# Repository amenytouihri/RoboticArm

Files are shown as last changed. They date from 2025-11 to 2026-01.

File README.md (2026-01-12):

# 🤖 Parallel Robotic Arm

A **2 Degree of Freedom (2-DOF)** robotic arm designed to draw shapes from a predefined set of points.
The system uses **two micro servo motors** for actuation, controlled by an **Arduino Uno** and an **L298N motor driver**.

Each arm segment has a **reach of 78 mm**, with a focus on tidy wiring, compact assembly, and stable mounting of all components.

## 🩺 Context

This project is developed under the **Applied Medical Robotics** module, with inspiration from **robotic-assisted surgical systems** such as:

* Eye dissection
* Colon dissection
* Microvascular / Reconstructive surgery

## ⚙️ Requirements

* **Robust** – stable operation and solid mechanical structure
* **Lightweight** – easy to move and mount
* **Precise** – smooth and accurate positioning
* **Creative** – adaptable to different control and testing scenarios

## 🧩 Components

* Arduino Uno
* L298N Motor Driver
* 2× EMG30 Motors
* Custom 3D-printed or laser-cut arm structure (78 mm reach per arm)

## 📐 Features

* Two-axis motion (2-DOF)
* Controlled shape drawing from coordinate data
* Modular design for experimentation
* Clean and secure wiring setup

## 👩🏻‍💻 Software Architecture 
Python GUI
   ↓  (Serial: "A,B")
Arduino Controller
   ├── Encoder Reading
   ├── Angle Estimation (Virtual Target Generator)
   ├── PID Motor Control
   ├── DC Motors + Encoders
   └── Position Feedback

## 🛠️ CAD 
Link for the CAD files: https://a360.co/4qQ7mWJ

## 📄 License

This project is licensed under the [MIT License](https://choosealicense.com/licenses/mit/).

This project is part of the 7MRI0060 Applied Medical Robotics module @King's College London

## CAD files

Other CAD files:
CAD/ALL+COMPONENTS+TOGETHER.dwg
CAD/ALL+COMPONENTS+TOGETHER.f3z

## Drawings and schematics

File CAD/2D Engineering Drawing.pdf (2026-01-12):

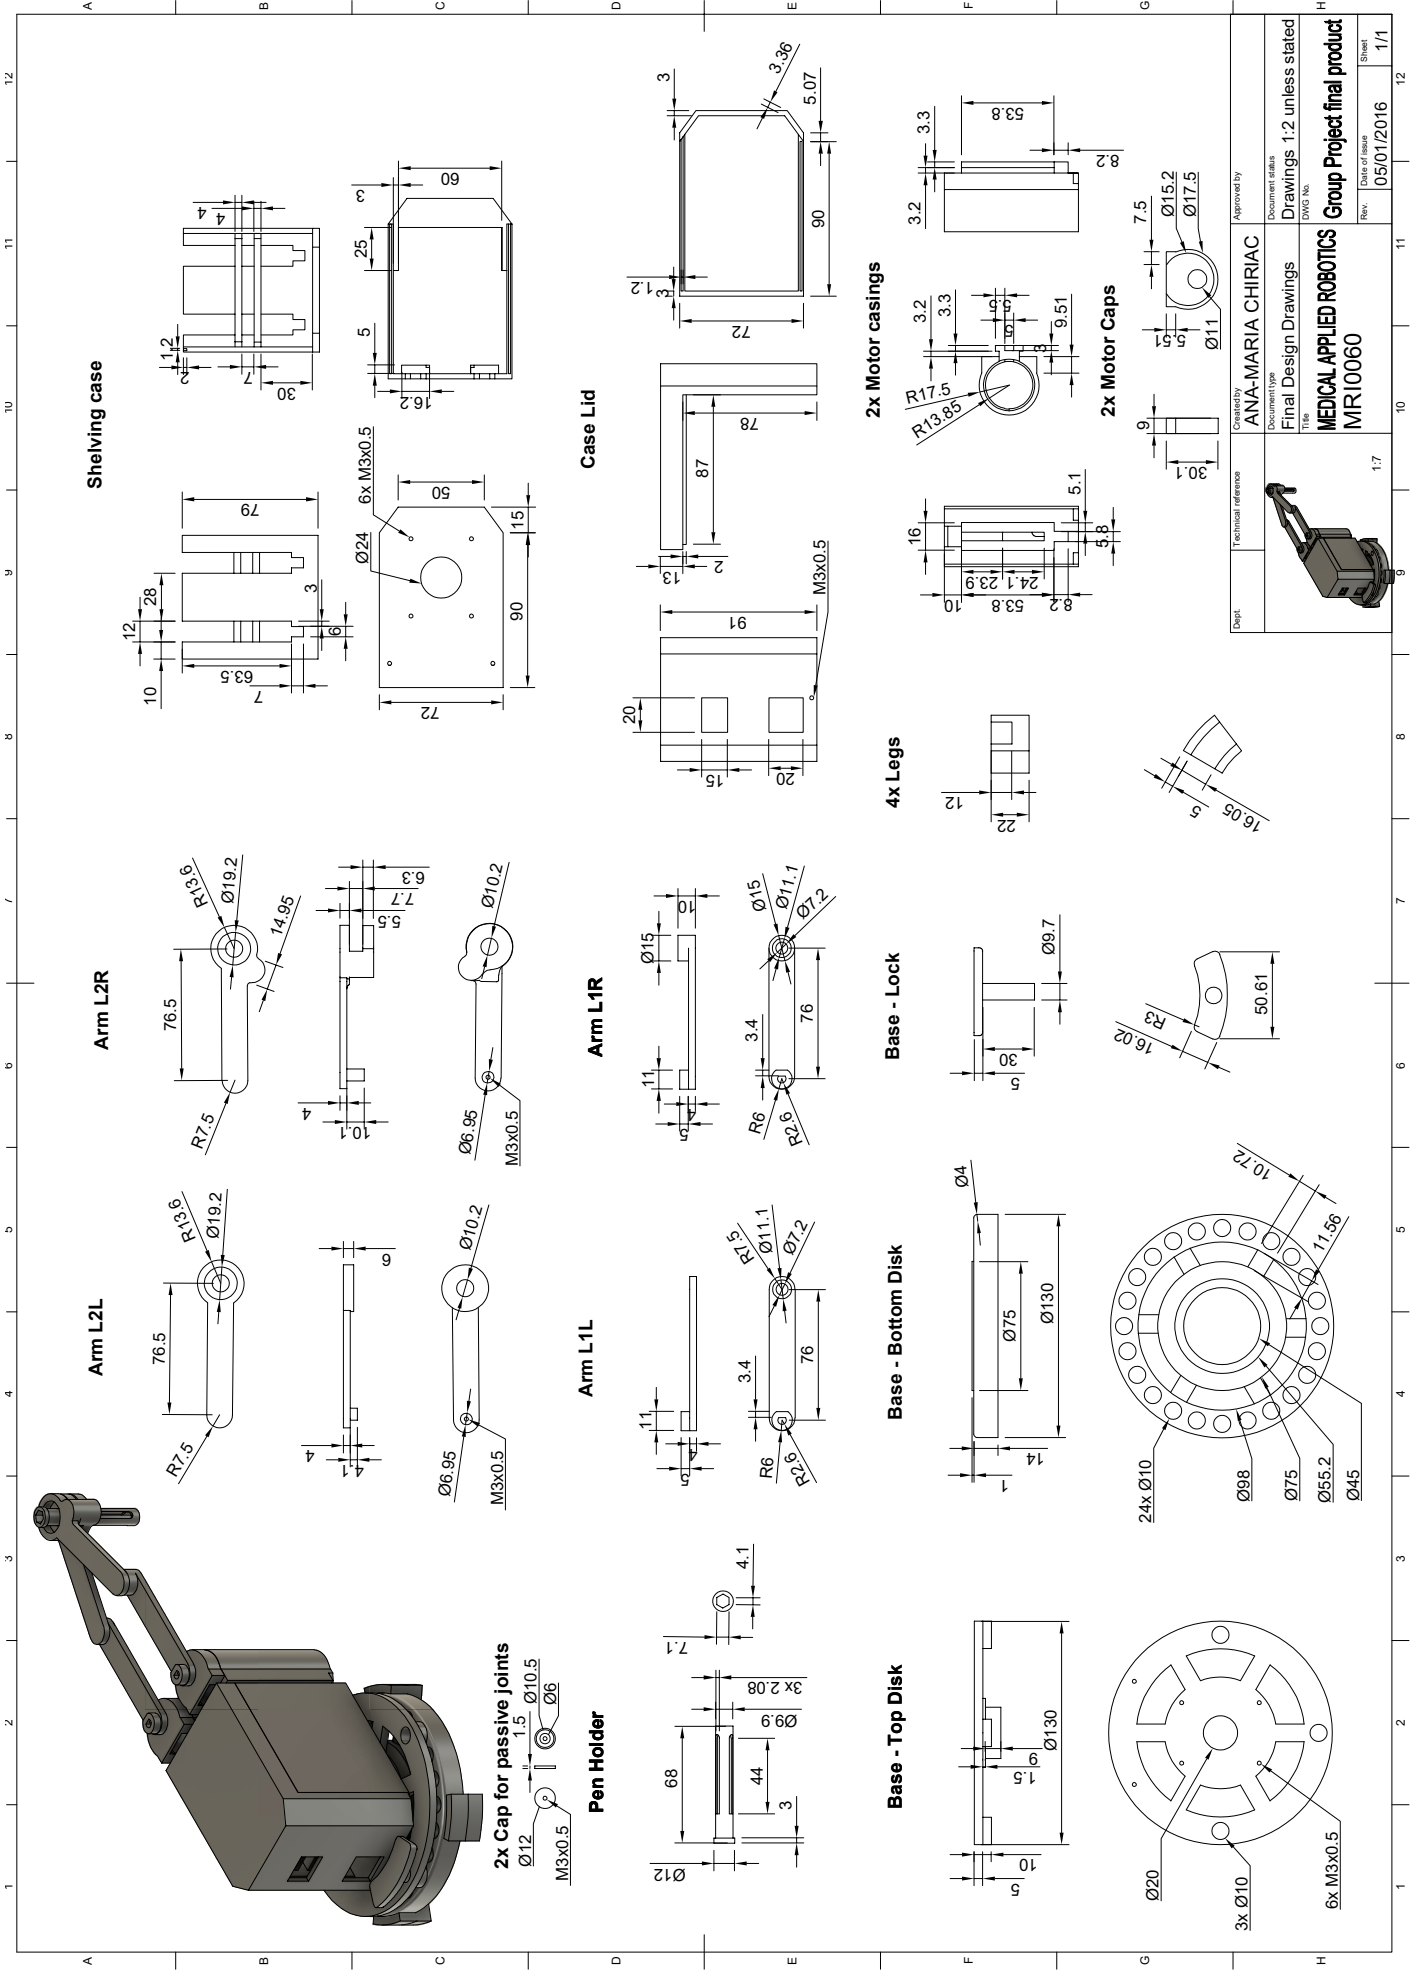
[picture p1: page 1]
4 1. Pen Holder; Ø6.95 Ø10.2 M3x0.5 Arm L1R 11 Ø15; 6. 3.476 Arm L2L; Ø10.2 Arm L1L 11

H Dept. Technical reference Created by Approved by Document type Document status Title DWG No. Rev. Date of issue Sheet 05/01/2016 Drawings 1:2 unless stated Final Design Drawings 1/1 MRI0060 1:7 ANA-MARIA CHIRIAC Ø130

1 .56 Base - Top Disk Base - Bottom Disk Ø9.7

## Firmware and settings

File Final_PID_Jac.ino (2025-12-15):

/*
  ==============================================================
  Dual-Motor Robotic Arm Controller
  Version: Virtual Target Enabled
  ==============================================================
  - Controls TWO DC motors (Motor A & Motor B)
  - Each motor has an encoder for position feedback
  - Uses PID control to reach desired angles
  - Uses a "virtual target" to avoid sudden jumps
  - Receives commands from a PC (e.g. Python GUI) via Serial:
        "angleA,angleB"
  - Designed for linked / parallel robotic arms
*/

///////////////////////////////////////////////////////////////
// ENCODER SETTINGS
///////////////////////////////////////////////////////////////

// Encoder pin definitions
// Each motor has a quadrature encoder (A + B channels)
#define ENC_A_A 2   // Encoder A, channel A (interrupt pin)
#define ENC_A_B 4   // Encoder A, channel B
#define ENC_B_A 3   // Encoder B, channel A (interrupt pin)
#define ENC_B_B 6   // Encoder B, channel B

// Encoder resolution
// CPR = Counts Per Revolution (measured experimentally)
const float CPR = 187.0;

// Conversion factor: encoder ticks → degrees
// one encoder tick corresponds to this many degrees of shaft rotation.
// CPR (Counts Per Revolution) = Number of encoder ticks generated for one full rotation
const float DEG_PER_TICK = 360.0 / CPR;

// Encoder counters (updated inside interrupts)
// volatile = tells compiler this can change at any time
volatile long counterA = 0;
volatile long counterB = 0;

// Encoder value at startup (used as "home" reference)
long homeCountA = 0;
long homeCountB = 0;

// Last encoder A-channel state (for direction detection)
int lastAState, lastBState;

// Current motor positions in degrees
// We ASSUME the physical arm is placed at 90° at startup
float positionA = 90.0;
float positionB = 90.0;

// Direction correction for each motor
// Use +1 or -1 depending on how the motor/encoder is mounted
const int DIR_SIGN_A = +1;
const int DIR_SIGN_B = -1;

// Zone where we enforce minimum PWM
// Prevents motors from stalling when error is still large
const float MOVE_ZONE = 3.0;

///////////////////////////////////////////////////////////////
// MOTOR SETTINGS
///////////////////////////////////////////////////////////////

// Motor A pins (H-bridge)
const int mA_in1 = 7;
const int mA_in2 = 8;
const int mA_pwm = 5;

// Motor B pins (H-bridge)
const int mB_in1 = 9;
const int mB_in2 = 10;
const int mB_pwm = 11;

///////////////////////////////////////////////////////////////
// PID SETTINGS
///////////////////////////////////////////////////////////////

// PID gains for Motor A
float KpA = 2.6455;
float KiA = 0.8;
float KdA = 0.1242;

// PID gains for Motor B
float KpB = 2.85;
float KiB = 0.6;
float KdB = 0.5;

// Small error range where motor is considered "close enough"
float deadzone = 0.2;

// PID memory terms
float prevErrorA = 0.0;
float integralA  = 0.0;
float prevErrorB = 0.0;
float integralB  = 0.0;

///////////////////////////////////////////////////////////////
// MOTION SMOOTHING (VIRTUAL TARGET SYSTEM)
///////////////////////////////////////////////////////////////

// Current PWM output values (for smooth ramping)
int pwmA_current = 0;
int pwmB_current = 0;

// PWM limits
const int MAX_PWM     = 100;
const int MIN_PWM     = 30;
const int pwmRampStep = 10;   // max PWM change per loop

// REAL target angles (from Serial commands)
float targetA  = 90.0;
float targetB  = 90.0;

// VIRTUAL target angles
// These slowly move toward the real target
float virtualA = 90.0;
float virtualB = 90.0;

// Control loop timing
const float LOOP_DT_SEC           = 0.05; // 50 ms loop
const float MAX_SPEED_DEG_PER_SEC = 10.0; // virtual motion speed

///////////////////////////////////////////////////////////////
// SYSTEM STATE
///////////////////////////////////////////////////////////////

// Prevents motors from moving until first Serial command arrives
bool firstCommandReceived = false;

// Onboard LED (optional debug)
const int ledPin = 13;

///////////////////////////////////////////////////////////////
// SETUP
///////////////////////////////////////////////////////////////
void setup() {

  // Start serial communication
  Serial.begin(115200);
  Serial.setTimeout(10);

  pinMode(ledPin, OUTPUT);

  // Encoder inputs
  pinMode(ENC_A_A, INPUT_PULLUP);
  pinMode(ENC_A_B, INPUT_PULLUP);
  pinMode(ENC_B_A, INPUT_PULLUP);
  pinMode(ENC_B_B, INPUT_PULLUP);

  // Read initial encoder states
  lastAState = digitalRead(ENC_A_A);
  lastBState = digitalRead(ENC_B_A);

  // Attach interrupts to encoder A channels
  attachInterrupt(digitalPinToInterrupt(ENC_A_A), updateEncoderA, CHANGE);
  attachInterrupt(digitalPinToInterrupt(ENC_B_A), updateEncoderB, CHANGE);

  // Motor outputs
  pinMode(mA_in1, OUTPUT);
  pinMode(mA_in2, OUTPUT);
  pinMode(mA_pwm, OUTPUT);

  pinMode(mB_in1, OUTPUT);
  pinMode(mB_in2, OUTPUT);
  pinMode(mB_pwm, OUTPUT);

  delay(300); // let system settle

  // Capture encoder values as "home"
  homeCountA = counterA;
  homeCountB = counterB;

  // Initialize all angles at 90°
  positionA = positionB = 90.0;
  targetA   = targetB   = 90.0;
  virtualA  = virtualB  = 90.0;

  Serial.println("System ready.");
}

///////////////////////////////////////////////////////////////
// MAIN LOOP
///////////////////////////////////////////////////////////////
void loop() {

  ///////////////////////////////////////////////////////////////
  // 1) READ SERIAL COMMAND
  ///////////////////////////////////////////////////////////////
  // Expected format: "angleA,angleB"
  if (Serial.available()) {
    String data = Serial.readStringUntil('\n');
    data.trim();
  /*  1) parses a serial command in the form angleA,angleB
      2)converts both values to numerical targets
      3)enables motion only after a valid command is received */ 
    int comma = data.indexOf(',');
    if (comma > 0) {
      targetA = data.substring(0, comma).toFloat();
      targetB = data.substring(comma + 1).toFloat();
      firstCommandReceived = true;
    }
  }

  // Safety: do nothing until first command arrives
  if (!firstCommandReceived) {
    analogWrite(mA_pwm, 0);
    analogWrite(mB_pwm, 0);
    return;
  }

  ///////////////////////////////////////////////////////////////
  //2) ENCODER → CURRENT POSITION
  ///////////////////////////////////////////////////////////////
  long rawA, rawB;
  // Local copies of encoder counters

  // Read encoder counts atomically
  noInterrupts();  //Temporarily pauses all interrupt service routines
  rawA = counterA; // Copies the current encoder counts
  rawB = counterB;
  interrupts(); //Restores normal interrupt operation
  // This was used bc "long" is multi-byte on Arduino ISRs could update it mid-read
  // Converts the raw encoder count of Motor into a real angular position in degrees
  //relative to a known starting position of 90°.
  positionA = 90.0 + DIR_SIGN_A * (rawA - homeCountA) * DEG_PER_TICK;
  positionB = 90.0 + DIR_SIGN_B * (rawB - homeCountB) * DEG_PER_TICK;

  ///////////////////////////////////////////////////////////////
  // 3) VIRTUAL TARGET RAMPING
  // Limit how fast the target angle can change per control loop
  // This prevents sudden jumps from IK and enforces a maximum angular speed
  ///////////////////////////////////////////////////////////////
  /*MAX_SPEED_DEG_PER_SEC = maximum allowed angular speed (degrees per second)
  LOOP_DT_SEC = duration of one control loop iteration (seconds)
  maxStep = maximum angle change allowed in one loop*/
  float maxStep = MAX_SPEED_DEG_PER_SEC * LOOP_DT_SEC;

  if (fabs(targetA - virtualA) > 0.01) {
    // Compute a bounded step toward the real target
    float step = constrain(targetA - virtualA, -maxStep, maxStep);
    // Move virtual target gradually
    virtualA += step;
  }

  if (fabs(targetB - virtualB) > 0.01) {
    float step = constrain(targetB - virtualB, -maxStep, maxStep);
    virtualB += step;
  }

  ///////////////////////////////////////////////////////////////
  // 4) PID CONTROL (USING VIRTUAL TARGETS)
  ///////////////////////////////////////////////////////////////
  /*runs the full PID control loop for Motor, 
  using the virtual target angle and the current measured position, 
  and directly drives the motor pins with smooth PWM output.  */
  controlMotor(
    virtualA, positionA,
    prevErrorA, integralA,
    pwmA_current,
    mA_in1, mA_in2, mA_pwm,
    KpA, KiA, KdA
  );

  controlMotor(
    virtualB, positionB,
    prevErrorB, integralB,
    pwmB_current,
    mB_in1, mB_in2, mB_pwm,
    KpB, KiB, KdB
  );

  ///////////////////////////////////////////////////////////////
  // 5) DEBUG OUTPUT
  ///////////////////////////////////////////////////////////////
  Serial.print("A: ");
  Serial.print(positionA, 2);
  Serial.print(" | PWM: ");
  Serial.print(pwmA_current);
  Serial.print(" | VTarget: ");
  Serial.print(virtualA, 2);
  Serial.print(" | Error: ");
  Serial.print(virtualA - positionA, 2);

  Serial.print(" || B: ");
  Serial.print(positionB, 2);
  Serial.print(" | PWM: ");
  Serial.print(pwmB_current);
  Serial.print(" | VTarget: ");
  Serial.print(virtualB, 2);
  Serial.print(" | Error: ");
  Serial.println(virtualB - positionB, 2);

  delay(50); // loop timing
}

///////////////////////////////////////////////////////////////
// PID MOTOR CONTROL FUNCTION
///////////////////////////////////////////////////////////////
/*
one complete closed-loop controller for a single motor:
  compares desired angle vs measured angle
  computes a PID control output
  smooths the PWM
  sets motor direction and speed via an H-bridge
*/ 
void controlMotor(
  float target, float position,
  float &prevError, float &integral,
  int &pwmCurrent,
  int in1, int in2, int pwmPin,
  float Kp, float Ki, float Kd
) {
  float error = target - position;
  float derivative = error - prevError;

  // Deadzone: stop motor if close enough
  if (fabs(error) < deadzone) {
    analogWrite(pwmPin, 0);
    digitalWrite(in1, LOW);
    digitalWrite(in2, LOW);
    pwmCurrent = 0;
    prevError = error;
    return;
  }

  /* Integral term with anti-windup
  accumulates the control error over time to eliminate steady-state error, 
  while preventing the integral term from growing too large, 
  which could destabilize the system.
  */ 
  integral += error * LOOP_DT_SEC;
  integral = constrain(integral, -20.0, 20.0);

  // PID equation
  float output = Kp * error + Ki * integral + Kd * derivative;
  output = constrain(output, -MAX_PWM, MAX_PWM);

  /* Smooth PWM ramping
  This block prevents sudden jumps in motor power 
  by limiting how fast the PWM value is allowed to change from one control loop to the next.
  pwmCurrent += updates PWM slowly over multiple iterations
  providing smooth acceleration = protecting the mechanical system*/ 
  int desired = (int)output;
  pwmCurrent += constrain(desired - pwmCurrent, -pwmRampStep, pwmRampStep);

  /*ensures the motor receives enough power to actually move when it is far from the target
  fabs(error) >= MOVE_ZONE = the joint is still far from the target
  pwmValue < MIN_PWM = commanded power is too low to overcome friction
  => force PWM up to a minimum value that guarantees motion*/ 
  int pwmValue = abs(pwmCurrent);
  if (fabs(error) >= MOVE_ZONE && pwmValue < MIN_PWM) pwmValue = MIN_PWM;
  pwmValue = constrain(pwmValue, 0, MAX_PWM);

  // Set motor direction
  if (pwmCurrent > 0) {
    digitalWrite(in1, HIGH);
    digitalWrite(in2, LOW);
  } else {
    digitalWrite(in1, LOW);
    digitalWrite(in2, HIGH);
  }

  analogWrite(pwmPin, pwmValue);
  prevError = error;
}

///////////////////////////////////////////////////////////////
// ENCODER INTERRUPT SERVICE ROUTINES
///////////////////////////////////////////////////////////////
// Reads quadrature encoder channels to update position and direction
void updateEncoderA() {
  // Read encoder channels
  int a = digitalRead(ENC_A_A);
  int b = digitalRead(ENC_A_B);
  // Process only on state change of channel A
  if (a != lastAState) {
    // Determine direction using channel B
    counterA += (a == b) ? 1 : -1;
    lastAState = a;
  }
}

void updateEncoderB() {
  int a = digitalRead(ENC_B_A);
  int b = digitalRead(ENC_B_B);
  if (a != lastBState) {
    counterB += (a == b) ? 1 : -1;
    lastBState = a;
  }
}

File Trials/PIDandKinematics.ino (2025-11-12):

/*
   ==============================================================
   Dual-Motor Robotic Arm Prototype + Serial Angle Input
   ==============================================================
   Purpose:
     - Controls two DC motors (Motor A & Motor B) using encoders
     - Uses PID control for smooth, precise motion
     - Gradually ramps targets (soft motion transitions)
     - Receives target angles (A,B) from Serial input (e.g. Python)
       → Format: "angleA,angleB\n"
     - Designed for a 2-DOF robotic arm joint control demo
*/

// -------------------- ENCODER SETUP --------------------
// Each encoder provides feedback on motor shaft rotation.
// Two channels (A & B) per encoder let us detect direction.

// Encoder pin assignments
#define ENC_A_A 2
#define ENC_A_B 4
#define ENC_B_A 3
#define ENC_B_B 6

// Encoder and gearbox parameters
const float PPR = 600.0;  // Pulses per revolution (encoder)
const float GR  = 30.0;   // Gear ratio (reduction gear)

// Encoder position counters (updated in interrupt routines)
volatile long counterA = 0;
volatile long counterB = 0;

// Used to detect encoder direction changes
int aLastState, bLastState;

// Computed angular positions (in degrees)
float positionA = 0.0;
float positionB = 0.0;


// -------------------- MOTOR SETUP --------------------
// Motor driver pin connections (e.g. L298N, TB6612, etc.)
const int mA_pinIn1 = 7;   // Direction pin 1 for Motor A
const int mA_pinIn2 = 8;   // Direction pin 2 for Motor A
const int mA_pinEnA = 5;   // PWM enable pin (speed control)

const int mB_pinIn3 = 9;   // Direction pin 1 for Motor B
const int mB_pinIn4 = 10;  // Direction pin 2 for Motor B
const int mB_pinEnB = 11;  // PWM enable pin (speed control)


// -------------------- PID CONFIGURATION --------------------
// PID constants control responsiveness and stability
float Kp = 3.0;     // Proportional term → how strongly error is corrected
float Ki = 0.01;    // Integral term → reduces steady-state error
float Kd = 0.1;     // Derivative term → dampens oscillation

float threshold = 1.0; // Dead zone: when error < 1°, motor stops

// PID memory variables (for each motor)
float prevErrorA = 0.0, integralA = 0.0;
float prevErrorB = 0.0, integralB = 0.0;


// -------------------- MOTION SMOOTHING --------------------
// Prevents jerky motor movement when changing targets

int pwmA_current = 0;    // Current PWM value for Motor A
int pwmB_current = 0;    // Current PWM value for Motor B
int pwmRampStep = 10;    // Maximum PWM change per loop iteration

float virtualTargetA = 0.0; // Gradually approaches targetA
float virtualTargetB = 0.0; // Gradually approaches targetB

// Actual target angles (updated from Serial commands)
float targetA = 90.0;    // Default target for Motor A
float targetB = 180.0;   // Default target for Motor B

// Step size for virtual target updates
float step = 1.5;        // Smaller = smoother motion


// -------------------- SERIAL INPUT VARIABLES --------------------
int ledPin = 13;         // LED feedback indicator
float angle1Value;       // Parsed angle for motor A
float angle2Value;       // Parsed angle for motor B
String data_new;         // For printing processed serial data


// -------------------- SETUP --------------------
void setup() {
  Serial.begin(115200);  // Fast baud rate for real-time control
  Serial.setTimeout(10); // Short serial timeout
  pinMode(ledPin, OUTPUT);

  // --- Setup encoder pins ---
  pinMode(ENC_A_A, INPUT_PULLUP);
  pinMode(ENC_A_B, INPUT_PULLUP);
  pinMode(ENC_B_A, INPUT_PULLUP);
  pinMode(ENC_B_B, INPUT_PULLUP);

  // Read initial encoder states
  aLastState = digitalRead(ENC_A_A);
  bLastState = digitalRead(ENC_B_A);

  // Attach interrupts for encoder channel A on both motors
  attachInterrupt(digitalPinToInterrupt(ENC_A_A), updateEncoderA, CHANGE);
  attachInterrupt(digitalPinToInterrupt(ENC_B_A), updateEncoderB, CHANGE);

  // --- Setup motor driver pins ---
  pinMode(mA_pinIn1, OUTPUT);
  pinMode(mA_pinIn2, OUTPUT);
  pinMode(mA_pinEnA, OUTPUT);
  pinMode(mB_pinIn3, OUTPUT);
  pinMode(mB_pinIn4, OUTPUT);
  pinMode(mB_pinEnB, OUTPUT);
}


// -------------------- MAIN LOOP --------------------
void loop() {

  // ======================================================
  // 1 RECEIVE SERIAL INPUT: "angleA,angleB"
  // ======================================================
  if (Serial.available() > 0) {
    String data = Serial.readStringUntil('\n'); // read until newline
    data.trim(); // remove any spaces or stray chars
    int commaIndex = data.indexOf(',');

    if (commaIndex > 0) {
      // Split string into two angle parts
      String angle1Str = data.substring(0, commaIndex);
      String angle2str = data.substring(commaIndex + 1);

      // Optional: add a small random scaling factor
      // (This seems like experimental jitter – can be removed safely)
      float r = (random(0, 100) / 1000.0) + 1; // 1.000–1.099
      angle1Value = angle1Str.toFloat() * r;
      angle2Value = angle2str.toFloat() * r;

      // Keep a readable record of received data
      data_new = String(angle1Value) + "," + String(angle2Value);

      // Update motor targets
      targetA = angle1Value;
      targetB = angle2Value;

      // Debug print
      Serial.print("Received angles: ");
      Serial.println(data);
      Serial.print("Applied with variation: ");
      Serial.println(data_new);

      // Blink LED for confirmation
      digitalWrite(ledPin, HIGH);
      delay(100);
      digitalWrite(ledPin, LOW);
    }
  }

  // ======================================================
  // 2️ COMPUTE ENCODER-BASED POSITIONS
  // ======================================================
  // Convert encoder counts into motor output shaft degrees.
  // Formula: (count / (PPR * GearRatio)) * 360°
  positionA = -((float)counterA / (PPR * GR)) * 360.0;
  positionB = ((float)counterB / (PPR * GR)) * 360.0;


  // ======================================================
  // 3️ UPDATE "VIRTUAL" TARGETS GRADUALLY
  // ======================================================
  // Instead of jumping directly to targetA/B,
  // we incrementally step toward it to reduce jerk.
  if (abs(virtualTargetA - targetA) > 0.1)
    virtualTargetA += (virtualTargetA < targetA ? step : -step);

  if (abs(virtualTargetB - targetB) > 0.1)
    virtualTargetB += (virtualTargetB < targetB ? step : -step);


  // ======================================================
  // 4️ PID CONTROL: MOTOR A
  // ======================================================
  float errorA = virtualTargetA - positionA; // Difference between desired and actual
  integralA += errorA;                       // Integrate error over time
  float derivativeA = errorA - prevErrorA;   // Rate of error change

  // PID output (control signal)
  float outputA = Kp * errorA + Ki * integralA + Kd * derivativeA;
  outputA = constrain(outputA, -255, 255);   // Limit PWM
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

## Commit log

2025-12-15 Add software architecture section to README
    Added a section detailing the software architecture, including components and data flow.
2025-12-15 Fix SIGN_A value for calibration
    [Python_Jac.py]
2026-01-12 Rename 2D Engineering Drawing.pdf to CAD/2D Engineering Drawing.pdf
